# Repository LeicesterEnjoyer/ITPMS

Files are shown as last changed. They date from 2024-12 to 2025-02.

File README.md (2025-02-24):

# ITPMS

## A lightweight, energy-efficient **Improved TPMS with integrated tire wear assistant (ITPMS)**. Designed for universal compatibility and precision.

## 🔥 Key Features

- **🏋️ Ultra-Compact Design**  
    Minimal weight (<30g) ensures compatibility with most tires without affecting balance.

- **📡 Autonomous Operation**  
    Wakes up via accelerometer motion detection → close to none battery drain when stationary.

- **📊 Fast And Precise**  
    Uses device computing from sensors such as:
    - Pressure sensor
    - Temperature sensor (built into the MCU)
    - 3-axis accelerometer
    - Hall effect sensor

- **🔋 10-Year Battery Life**  
    Has low-powered elements and works only while the vehicle is moving.

- **🎯 Hall Effect Initialization**  
    Quick pairing with magnetic TPMS initializing pen.

## 🛠 How It Works

### Installation & Activation

1. **Open** remove the tire from the rim.
2. **Mount** the TPMs on the stem valve inside the tire .
3. **Wake & Pair** the TPMs with the magnetic TPMS initializing pen.
4. **Drive** to see the real time pressure and temperature changes.

### Data Transmission

| Trigger | Action |
|---|---|
| > 5% pressure deviation from last read | Instant RF alert to ECU |
| > 5% temperature deviation from last read | Instant RF alert to ECU |
| 10s without any significant changes | Keep-alive ping |

## 🔍 Code library

ITPMS/  
├── [Assistant/](Assistant/)&nbsp;&nbsp;&nbsp;&nbsp;&nbsp;&nbsp;&nbsp;&nbsp;&nbsp;&nbsp;&nbsp;&nbsp;&nbsp;&nbsp;&nbsp;&nbsp;&nbsp;&nbsp;&nbsp;&nbsp;&nbsp;&nbsp;&nbsp;&nbsp;&nbsp;&nbsp;&nbsp;&nbsp;&nbsp;&nbsp;&nbsp;&nbsp;# All files for the tire wear assistant.  
│&nbsp;&nbsp;&nbsp;├── [assets/](Assistant/assets/)&nbsp;&nbsp;&nbsp;&nbsp;&nbsp;&nbsp;&nbsp;&nbsp;&nbsp;&nbsp;&nbsp;&nbsp;&nbsp;&nbsp;&nbsp;&nbsp;&nbsp;&nbsp;&nbsp;&nbsp;&nbsp;&nbsp;&nbsp;&nbsp;&nbsp;&nbsp;&nbsp;&nbsp;&nbsp;&nbsp;&nbsp;# Assets for the UI.  
│&nbsp;&nbsp;&nbsp;├── [CSVhandling/](Assistant/CSVhandling/)  
│&nbsp;&nbsp;&nbsp;│&nbsp;&nbsp;&nbsp;&nbsp;|── [CSVmanager.py](Assistant/CSVhandling/CSVmanager.py)&nbsp;&nbsp;&nbsp;&nbsp;&nbsp;&nbsp;&nbsp;&nbsp;&nbsp;&nbsp;&nbsp;&nbsp;# Read and write operations for csv files.  
│&nbsp;&nbsp;&nbsp;│&nbsp;&nbsp;&nbsp;└── [DataGenerator.py](Assistant/CSVhandling/DataGenerator.py)&nbsp;&nbsp;&nbsp;&nbsp;&nbsp;&nbsp;&nbsp;&nbsp;# Generator for (TPMs) tire data.  
│&nbsp;&nbsp;&nbsp;│  
│&nbsp;&nbsp;&nbsp;├── [Data/](Assistant/Data/)&nbsp;&nbsp;&nbsp;&nbsp;&nbsp;&nbsp;&nbsp;&nbsp;&nbsp;&nbsp;&nbsp;&nbsp;&nbsp;&nbsp;&nbsp;&nbsp;&nbsp;&nbsp;&nbsp;&nbsp;&nbsp;&nbsp;&nbsp;&nbsp;&nbsp;&nbsp;&nbsp;&nbsp;&nbsp;&nbsp;&nbsp;&nbsp;# Data files for the different tire types and seasons.  
│&nbsp;&nbsp;&nbsp;├── [Tests/](Assistant/Tests/)&nbsp;&nbsp;&nbsp;&nbsp;&nbsp;&nbsp;&nbsp;&nbsp;&nbsp;&nbsp;&nbsp;&nbsp;&nbsp;&nbsp;&nbsp;&nbsp;&nbsp;&nbsp;&nbsp;&nbsp;&nbsp;&nbsp;&nbsp;&nbsp;&nbsp;&nbsp;&nbsp;&nbsp;&nbsp;&nbsp;&nbsp;&nbsp;# Tests for the functionalities of the TPMs classes.  
│&nbsp;&nbsp;&nbsp;├── [TPMsHandling/](Assistant/TPMsHandling/)  
│&nbsp;&nbsp;&nbsp;│&nbsp;&nbsp;&nbsp;&nbsp;|── [Tire.py](Assistant/TPMsHandling/Tire.py)&nbsp;&nbsp;&nbsp;&nbsp;&nbsp;&nbsp;&nbsp;&nbsp;&nbsp;&nbsp;&nbsp;&nbsp;&nbsp;&nbsp;&nbsp;&nbsp;&nbsp;&nbsp;&nbsp;&nbsp;&nbsp;&nbsp;&nbsp;&nbsp;&nbsp;&nbsp;# Represents the tire (TPMs).  
│&nbsp;&nbsp;&nbsp;│&nbsp;&nbsp;&nbsp;└── [Tires.py](Assistant/TPMsHandling/Tires.py)&nbsp;&nbsp;&nbsp;&nbsp;&nbsp;&nbsp;&nbsp;&nbsp;&nbsp;&nbsp;&nbsp;&nbsp;&nbsp;&nbsp;&nbsp;&nbsp;&nbsp;&nbsp;&nbsp;&nbsp;&nbsp;&nbsp;&nbsp;&nbsp;# Represents the tire complect of the vehicle.  
│&nbsp;&nbsp;&nbsp;│  
│&nbsp;&nbsp;&nbsp;├── [Main.py](Assistant/Main.py)&nbsp;&nbsp;&nbsp;&nbsp;&nbsp;&nbsp;&nbsp;&nbsp;&nbsp;&nbsp;&nbsp;&nbsp;&nbsp;&nbsp;&nbsp;&nbsp;&nbsp;&nbsp;&nbsp;&nbsp;&nbsp;&nbsp;&nbsp;&nbsp;&nbsp;&nbsp;&nbsp;&nbsp;# Runs the needed code and tests.  
│&nbsp;&nbsp;&nbsp;└── [TireAssistantGUI.py](Assistant/TireAssistantGUI.py)&nbsp;&nbsp;&nbsp;&nbsp;&nbsp;&nbsp;&nbsp;&nbsp;&nbsp;&nbsp;# UI for the assistant. (*Run the file to start it.)  
│  
├── [CAD/](CAD/)&nbsp;&nbsp;&nbsp;&nbsp;&nbsp;&nbsp;&nbsp;&nbsp;&nbsp;&nbsp;&nbsp;&nbsp;&nbsp;&nbsp;&nbsp;&nbsp;&nbsp;&nbsp;&nbsp;&nbsp;&nbsp;&nbsp;&nbsp;&nbsp;&nbsp;&nbsp;&nbsp;&nbsp;&nbsp;&nbsp;&nbsp;&nbsp;&nbsp;&nbsp;&nbsp;&nbsp;&nbsp;&nbsp;# KiCad models of the pcb.  
├── [Datasheets/](Datasheets/)&nbsp;&nbsp;&nbsp;&nbsp;&nbsp;&nbsp;&nbsp;&nbsp;&nbsp;&nbsp;&nbsp;&nbsp;&nbsp;&nbsp;&nbsp;&nbsp;&nbsp;&nbsp;&nbsp;&nbsp;&nbsp;&nbsp;&nbsp;&nbsp;&nbsp;&nbsp;&nbsp;# Datasheets of all components used in the pcb.  
├── [TPMS&TPMs/](TPMS&TPMs/)&nbsp;&nbsp;&nbsp;&nbsp;&nbsp;&nbsp;&nbsp;&nbsp;&nbsp;&nbsp;&nbsp;&nbsp;&nbsp;&nbsp;&nbsp;&nbsp;&nbsp;&nbsp;&nbsp;&nbsp;&nbsp;&nbsp;&nbsp;&nbsp;# All files and libraries used by the hardware.  
│&nbsp;&nbsp;&nbsp;├── [Code](TPMS&TPMs/Code/)/  
│&nbsp;&nbsp;&nbsp;│&nbsp;&nbsp;&nbsp;&nbsp;|── [Receiver.ino](TPMS&TPMs/Code/Receiver.ino)&nbsp;&nbsp;&nbsp;&nbsp;&nbsp;&nbsp;&nbsp;&nbsp;&nbsp;&nbsp;&nbsp;&nbsp;&nbsp;&nbsp;&nbsp;&nbsp;&nbsp;# Receiver algorithm.  
│&nbsp;&nbsp;&nbsp;│&nbsp;&nbsp;&nbsp;└── [Transmitter.ino](TPMS&TPMs/Code/Transmitter.ino)&nbsp;&nbsp;&nbsp;&nbsp;&nbsp;&nbsp;&nbsp;&nbsp;&nbsp;&nbsp;&nbsp;&nbsp;# Transmitter algorithm.  
│&nbsp;&nbsp;&nbsp;├── [Libraries/](TPMS&TPMs/Libraries/)  
│&nbsp;&nbsp;&nbsp;│&nbsp;&nbsp;&nbsp;&nbsp;├── [Receiver/](TPMS&TPMs/Libraries/Receiver/)&nbsp;&nbsp;&nbsp;&nbsp;&nbsp;&nbsp;&nbsp;&nbsp;&nbsp;&nbsp;&nbsp;&nbsp;&nbsp;&nbsp;&nbsp;&nbsp;&nbsp;&nbsp;&nbsp;&nbsp;# Receiver libraries.  
│&nbsp;&nbsp;&nbsp;│&nbsp;&nbsp;&nbsp;&nbsp;├── [TPMs/](TPMS&TPMs/Libraries/TPMs/)&nbsp;&nbsp;&nbsp;&nbsp;&nbsp;&nbsp;&nbsp;&nbsp;&nbsp;&nbsp;&nbsp;&nbsp;&nbsp;&nbsp;&nbsp;&nbsp;&nbsp;&nbsp;&nbsp;&nbsp;&nbsp;&nbsp;&nbsp;&nbsp;# Transmitter libraries.  
│&nbsp;&nbsp;&nbsp;│&nbsp;&nbsp;&nbsp;&nbsp;└── [TPMS_structures.h](TPMS&TPMs/Libraries/TPMS_structures.h)&nbsp;&nbsp;&nbsp;&nbsp;&nbsp;# Common configuration.  
│  
├── [LICENSE](LICENSE)  
├── [README.md](README.md)&nbsp;&nbsp;&nbsp;&nbsp;&nbsp;&nbsp;&nbsp;&nbsp;&nbsp;&nbsp;&nbsp;&nbsp;&nbsp;&nbsp;&nbsp;&nbsp;&nbsp;&nbsp;&nbsp;&nbsp;&nbsp;&nbsp;&nbsp;&nbsp;&nbsp;&nbsp;# You're here!  
└── [requirements.txt](requirements.txt)&nbsp;&nbsp;&nbsp;&nbsp;&nbsp;&nbsp;&nbsp;&nbsp;&nbsp;&nbsp;&nbsp;&nbsp;&nbsp;&nbsp;&nbsp;&nbsp;&nbsp;&nbsp;&nbsp;&nbsp;# Python dependencies.  

## 🔑 Setup

### Assistant

Run this command to download the needed dependencies:
```sh
pip install -r .requirements.txt
```
After that you can run the UI with:
```sh
python Assistant/TireAssistantGUI.py
```

### TPMS & TPMs

The software must be flashed on a special TPMs via SPI programmer. From there you have to follow the steps in [Installation & Activation](#installation--activation) an you will be ready to use it.

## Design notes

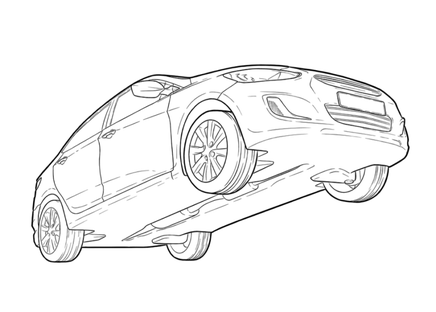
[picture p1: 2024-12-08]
Assistant/assets/image.png

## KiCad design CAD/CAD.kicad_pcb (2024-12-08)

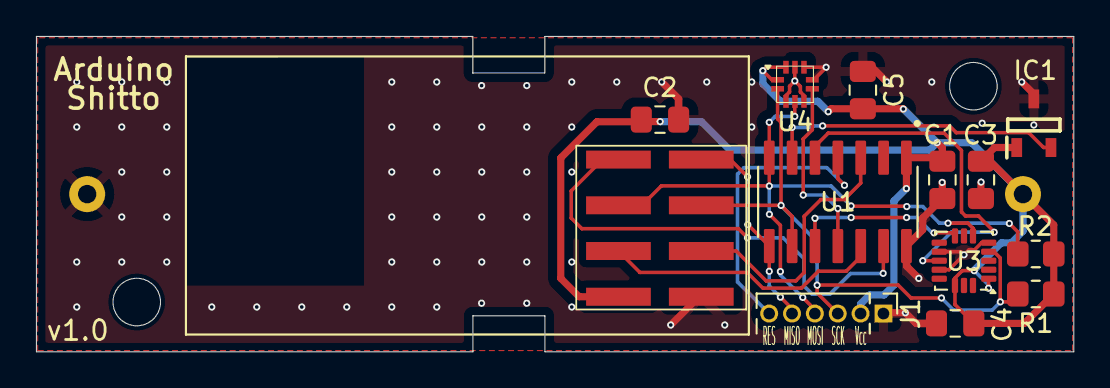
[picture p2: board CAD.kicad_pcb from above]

Board: 2 copper layers, 57.6 x 17.5 mm, 14 parts (1 on the bottom side), 13 nets.

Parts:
BT1: 2460; BAT_2460
C1, C3, C4, C5: 100nF; C_0805_2012Metric_Pad1.18x1.45mm_HandSolder
C2: 10µF; C_0805_2012Metric_Pad1.18x1.45mm_HandSolder
IC1: Si7201-B-04-IV; SOT95P275X125-3N
J1: Conn_01x06_Pin; PinHeader_1x06_P1.27mm_Vertical
R1, R2: 10kΩ; R_0805_2012Metric_Pad1.20x1.40mm_HandSolder
U1: ATTINY84-20SSU; SOIC127P600X175-14N
U2: NRF24L01_Breakout; nRF24L01_Breakout
U3: LIS3DH; LGA-16_3x3mm_P0.5mm_LayoutBorder3x5y
U4: ILPS22QS; ILPS22QSTR

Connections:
3.6V: BT1.P, C1.2, C2.2, C3.2, C4.2, C5.2, IC1.1 (VDD), J1.2, R1.1, R2.1, U1.1 (VCC), U2.2 (VCC), U3.1 (VDD_IO), U3.14 (VDD), U4.1 (Vdd_IO), U4.10 (Vdd)
/CE: U1.3 (PB1), U2.3 (CE)
/CS/A: U1.10 (PA3), U3.8 (CS)
/CS/P: U1.11 (PA2), U4.6 (CS)
/CS/RF: U1.12 (PA1), U2.4 (~CSN)
/INT_ACC: U1.5 (PB2), U3.11 (INT1)
/INT_HALL: IC1.2 (OUT1), U1.6 (PA7)
/IRQ: U1.13 (PA0), U2.8 (IRQ)
/MISO: J1.5, U1.8 (PA5), U2.7 (MISO)
/MOSI: J1.4, R2.2, U1.7 (PA6), U2.6 (MOSI), U3.6 (SDI), U4.4 (SDA)
/RESET: J1.6, U1.4 (PB3)
/SCK: J1.3, R1.2, U1.9 (PA4), U2.5 (SCK), U3.4 (SPC), U4.2 (SCK)
GND: BT1.N, C1.1, C2.1, C3.1, C4.1, C5.1, IC1.3 (GND), J1.1, U1.14 (GND), U2.1 (GND), U3.5 (GND), U3.10 (GND), U3.12 (GND), U4.3 (RES), U4.5 (AH2/QVAR2), U4.7 (AH1/QVAR1), U4.8 (GND_IO), U4.9 (GND)

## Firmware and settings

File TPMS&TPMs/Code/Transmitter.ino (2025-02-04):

#include <TPMS_T_config.h>
#include <TPMS_structures.h>


RF24 radio(RF_CE, RF_CSN);

volatile bool hasToInit = true;
volatile uint8_t INTtrigger = 0, prevINTtrigger = 0;

struct {
  char code;
} ack;

void setupInterrupts() {
  cli();
  MCUCR |= (1 << ISC01); // Enable INT0 on falling edge.
  GIMSK |= (1 << INT0) | (1 << PCIE0); // Enable INT0 and pin change interrupts.

  PCMSK0 |= (1 << PCINT7); // Enable pin change interrupt on PA7.
  sei();
}

ISR(INT0_vect) {
  INTtrigger++;
}

ISR(PCINT0_vect) {
  hasToInit = true;
}

void setupMCU() {
  MCUCR |= (1 << SM1); // When "sleep" is executed the MCU goes in power down mode.

  ADMUX |= (1 << REFS1) | (1 << MUX5) | (1 << MUX1); // Enable the temperature sensor.
  ADCSRA = (1 << ADEN) | (1 << ADPS1) | (1 << ADPS0); // Enable the ADC with on 125kHz.

  // Configure pins.
  DDRA |= (1 << DDA3) | (1 << DDA2); // Configure CS/A and CS/P as outputs.
  PORTA |= (1 << PORTA3) | (1 << PORTA2); // Set CS on both I2C devices to 1.

  // Configure the INT0 as output.
  DDRB &= ~(1 << DDB2);
  PORTB |= (1 << PORTB2); // Enable internal pull-up resistor.

  setupInterrupts();
}

void sleepMCU() {
  MCUCR |= (1 << SE);
  __asm__ __volatile__("sleep");
  MCUCR &= ~(1 << SE);
}

void setupRF() {
  if (!radio.begin())
    PORTB |= (1 << PORTB0);

  radio.setChannel(CHANNEL);
  radio.setRadiation(RF24_PA_MIN, RF24_250KBPS);

  radio.setRetries(15, 15);
  radio.getDynamicPayloadSize();
  radio.enableAckPayload();
  // radio.setAutoAck(false);

  radio.openWritingPipe(identity.address);
  radio.stopListening();
}

void sleepRF() {
  radio.powerDown();
}

void wakeRF() {
  radio.powerUp();
}

void setupPressure() {
  writeRegister(PRESSURE_ADDR, 0x20, (1 << 6)); // Enable full scale mode (4060 hPa).
  writeRegister(PRESSURE_ADDR, 0x10, (1 << 4)); // Configure the pressure sensor with AVG = 4 and ODR = 4 Hz.
  writeRegister(PRESSURE_ADDR, 0x5F, 0x00); // Disable AH1/QVAR1 and AH2/QVAR2.
}

void sleepPressure() {
  writeRegister(PRESSURE_ADDR, 0x10, 0); // Writing '0000' in ODR configures the pressure sensor to power-down mode.
}

void wakePressure() {
  writeRegister(PRESSURE_ADDR, 0x10, (1 << 4)); // Configure the pressure sensor with AVG = 4 and ODR = 4 Hz.
}

void setupACC() {
  writeRegister(ACC_ADDR, 0x20, (1 << 5) | (1 << 3) | (1 << 1) | (1 << 0)); // Configure the accelerometer to work on Low-power mode (10 Hz) and enable it to work on Y and X axes.
  writeRegister(ACC_ADDR, 0x22, (1 << 6)); // Route interrupt to INT1 pin.
  writeRegister(ACC_ADDR, 0x30, (1 << 3) | (1 << 2) | (1 << 1) | (1 << 0)); // Configure INT1 to generate interrupt on movement on both axises.
  writeRegister(ACC_ADDR, 0x32, (1 << 2) | (1 << 1)); // Configure the sensitivity 96 mg @ ±2g.
  writeRegister(ACC_ADDR, 0x33, (1 << 0)); // Configure a 100 ms duration so the noise is ignored.
  writeRegister(ACC_ADDR, 0x26, (1 << 1)); // Configure INT polarity to active low.
}

void writeRegister(const byte address, const byte reg, const byte value) {
  Wire.begin();

  Wire.beginTransmission(address);
  Wire.write(reg);
  Wire.write(value);
  Wire.endTransmission();

  Wire.end();
}

byte readRegister(const byte address, const byte reg) {
  Wire.begin();

  Wire.beginTransmission(address);
  Wire.write(reg);
  Wire.endTransmission(false); // "False" keeps the connection open.
  
  Wire.requestFrom(address, 1);
  byte result = 0x00;
  if (Wire.available()) 
    result = Wire.read();
  
  Wire.end();
  return result;
}

void sleepTPMs() {
  sleepRF();
  sleepPressure();
  sleepMCU();
}

void getPressure() {
  uint16_t pressureSum = 0;
  
  for (uint8_t measCnt = 0; measCnt != NUMBER_OF_MEAS; ++measCnt) {
    // Use the given formula in the datasheet for pressure calculation.
    uint32_t pressure = (readRegister(PRESSURE_ADDR, 0x2A) << 16) | (readRegister(PRESSURE_ADDR, 0x29) << 8) | readRegister(PRESSURE_ADDR, 0x28);
    pressure /= 2048;
    pressure /= 10; // Convert to kPa.

    pressureSum += pressure;
  }

  payload.pressure = pressureSum / NUMBER_OF_MEAS >> 1; // >> 1 so it fits in 1 byte (406 kPa is the largest value).
}

void getTemp() {
  int16_t tempSum = 0;
  
  for (uint8_t measCnt = 0; measCnt != NUMBER_OF_MEAS; ++measCnt) {
    ADCSRA |= (1 << ADSC); // Begin measurement.
    while (ADCSRA & (1 << ADSC)); // Wait for measure (the ADCL bit returns to 0 ones the conversion is completed).

    tempSum += ((ADCH << 8) | ADCL);
  }

  payload.temp = tempSum / NUMBER_OF_MEAS - 44; // Using a temperature offset.
}

void gatherPayload() {
  getTemp();
  getPressure();
}

bool changeInPressureOrTemp() {
  static int8_t prevTemp = 0;
  static uint16_t prevPressure = 0;

  if (abs((payload.pressure << 1) - prevPressure) >= prevPressure * 0.05
      || abs(payload.temp - prevTemp) >= prevTemp * 0.05)
  {
    prevPressure = (payload.pressure << 1);
    prevTemp = payload.temp;
    
    return true;
  }
  
  return false;
}

void OVFcorrection(uint32_t *current_ms, uint32_t *keepAlive_ms, uint32_t *prevTemp_ms, uint32_t *prevPressure_ms, uint32_t *prevINT_ms) {
  if (*current_ms >= *keepAlive_ms)
    return;
    
  *current_ms = *keepAlive_ms = *prevTemp_ms = *prevPressure_ms = *prevINT_ms = 0;
}

void interruptCheck(const uint32_t current_ms, uint32_t *prevINT_ms) {
  if (INTtrigger <= prevINTtrigger) 
    return;
  
  prevINTtrigger++;
  *prevINT_ms = current_ms;
}

void setup() {
  // Setup debug pin.
  DDRB |= (1 << DDB0);
  PORTB &= ~(1 << PORTB0);

  setupMCU(); 
  setupRF();
  setupPressure();
  setupACC();
  
  sleepTPMs();
}

void loop() {
  static uint32_t current_ms = 0, keepAlive_ms = 0, prevTemp_ms = 0, prevPressure_ms = 0, prevINT_ms = 0;
  current_ms = millis();

  OVFcorrection(&current_ms, &keepAlive_ms, &prevTemp_ms, &prevPressure_ms, &prevINT_ms);
  
  if (!hasToInit) {
    interruptCheck(current_ms, &prevINT_ms);
    if (current_ms - prevINT_ms >= PREV_INT0_MS)
        sleepTPMs();
  }

  if (hasToInit)
    sendIdentity();

  if (current_ms - prevTemp_ms >= TEMP_MEAS_MS) {
    prevTemp_ms = current_ms;
    getTemp();

    if (changeInPressureOrTemp()) {
      keepAlive_ms = current_ms;
      sendPayload();
    }
  }

  if (current_ms - prevPressure_ms >= PRESSURE_MEAS_MS) {
    prevPressure_ms = current_ms;
    getPressure();

    if (changeInPressureOrTemp()) {
      keepAlive_ms = current_ms;
      sendPayload();
    }
  }

  if (current_ms - keepAlive_ms >= KEEP_ALIVE_MS) {
    keepAlive_ms = current_ms;

    gatherPayload();
    sendPayload();
  }
}

void sendIdentity() {
  wakeRF();

  if (!radio.write(&identity, sizeof(identity))
      || !radio.isAckPayloadAvailable()) 
    return;
  
  if (radio.getDynamicPayloadSize() == 1) {
    sleepTPMs();
    return;
  }

  radio.read(&identity, radio.getDynamicPayloadSize());
  
  radio.setRetries(identity.retransmitDelay, 15);
  radio.openWritingPipe(identity.address);

  hasToInit = false;
  sleepRF();
  return;
}

void sendPayload() {
  wakeRF();

  if (!radio.write(&payload, sizeof(payload))
      || !radio.isAckPayloadAvailable()) 
    return;

  radio.read(&ack, radio.getDynamicPayloadSize());

  sleepRF();
  return;
}

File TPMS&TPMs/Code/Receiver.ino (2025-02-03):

#include <Tires.h>
#include <TPMS_structures.h>


RF24 radio(RF_CE, RF_CSN);


void clearEEPROM() {
  for (uint16_t i = 0; i < EEPROM.length(); ++i) {
    if (EEPROM.read(i) == 0xFF)
      break;
    EEPROM.write(i, 0xFF);
  }
}

void removeGarbage() {
  byte garbage[32];
  radio.read(&garbage, radio.getDynamicPayloadSize());
}

void setup() {
  Serial.begin(9600);
  while (!Serial);

  randomSeed(analogRead(A0)); // Seed randomness with floating analog pin.

  // Begin communication with the RF module.
  if (!radio.begin())
    Serial.println("Couldn't establish connection with the RF module.");
  
  radio.setChannel(CHANNEL);
  radio.setRadiation(RF24_PA_MIN, RF24_250KBPS);

  radio.getDynamicPayloadSize();
  radio.enableAckPayload();
  // radio.setAutoAck(false);

  const byte broadAddress[ADDRESS_LEN] = {'B', 'R', 'O', 'A', 'D'};

  radio.openReadingPipe(0, broadAddress);
  radio.startListening();

  // For debugging purposes only.
  // clearEEPROM(); 

  Serial.println("Connection established!");
}

void loop() {
  static tires_t tires;
  static char tireComplect = '0';
  static const char* positions[] = {"front left", "front right", "rear right", "rear left"};
  uint8_t pipe;
  
  static uint32_t current_ms = 0, lastReceived_ms[TIRES] = { 0 };
  static bool isInitializing = true, reinitialize = false, isMoving = true, synchronized = true;
  
  // isMoving comes from the automobile itself and checks if we are moving so we can synchronize the time between recieves.
  if (!isMoving)
    synchronized = false;

  if (!synchronized && isMoving) {
    uint32_t syncTime = millis();

    for (uint8_t i = 0; i < TIRES; ++i) 
      lastReceived_ms[i] = syncTime;
    synchronized = true;
  }

  current_ms = millis();

  // Check for a message in the RX fifo.
  if (radio.available(&pipe)) {
    if (!isInitializing) {
      if (radio.getDynamicPayloadSize() != sizeof(payload)) {
        removeGarbage();
        return;
      }
      
      lastReceived_ms[pipe - 1] = current_ms;

      static uint16_t prevPressure = payload.pressure << 1;
      static int8_t prevTemp = payload.temp;

      // Receive payload from TPMs (a tire).
      memset(&payload, 0, sizeof(payload));
      radio.read(&payload, sizeof(payload));

      Serial.print("Rceived payload from ");
      Serial.print(positions[pipe - 1]);
      Serial.println(":");
      Serial.print("Temperature: ");
      Serial.println(payload.temp);
      Serial.print("Pressure: ");
      Serial.println((payload.pressure << 1) / 1000); // To convert back to kPa -> y = (x << 1) and than to bar -> (y / 100).

      if (abs(payload.pressure - prevPressure) >= prevPressure * 0.1
          || abs(payload.temp - prevTemp) >= abs(prevTemp) * 0.1)
      {
        Serial.println("<Warning on the infotainment>");
        Serial.print("Unusual temperature or pressure changes detected on the ");
        Serial.print(positions[pipe]);
        Serial.println(" tire!");
        Serial.println("Check if everything is fine, before continuing to drive!");
        Serial.println("<Waiting for driver to close the warning from the infotainment>");

        prevPressure = payload.pressure;
        prevTemp = payload.temp;
      }
    }

    // The initialization is enabled by the driver from the infotainment.
    else {
      static uint8_t position = 0;

      // Receive identity from TPMs (a tire).
      memset(&identity, 0, sizeof(identity));
      radio.read(&identity, sizeof(identity));

      // For debugging purposes only.
      Serial.println("Received identity: ");
      Serial.print("Address: ");
      Serial.println((char *)identity.address);
      Serial.print("Retransmit Delay: ");
      Serial.println((char *)identity.retransmitDelay);

      // Driver must choose the tire complect. Valid options: 's' - summer; 'w' - winter.
      if (tireComplect == '0') {
        Serial.println("<Warning on the infotainment>");
        Serial.println("Choose tire complect!");
        Serial.println("<Waiting for driver's decision from the infotainment>");
      }
       
    
      // Select tire complect if possible (if has been used before). If 'selectTires()' returns false save the corresponding marker.  
      if (!selectTires(&tires, tireComplect))
        if (tireComplect == 's')
          EEPROM.write(SUMMER_MARKER_ADDR, SUMMER_MARKER);
        else
          EEPROM.write(WINTER_MARKER_ADDR, WINTER_MARKER);

      // Check if the current tire is already in that position.
      if (!checkTirePosition(tires, position, identity.address)) {
        // Check if the tire address is "BROAD". If it is than the tire is being initialized for the first time.
        if (memcmp(identity.address, "BROAD", sizeof(identity.address)) == 0) {
          initTier(&tires, position); // Initialize the tire with its position and unique address.

          // Load the initialized values in the identity.
          memset(&identity, 0, sizeof(identity));
          memcpy(identity.address, tires.tire[position].address, ADDRESS_LEN);
          identity.retransmitDelay = tires.tire[position].retransmitDelay;

          radio.writeAckPayload(0, &identity, sizeof(identity)); // Return the ACK with the initialized identity.
          radio.openReadingPipe(position + 1, tires.tire[position].address); // Open a new pipe for secure communication with the tire.
        }
        // If the address isn's "BROAD" the tire has been initialized before.
        else {
          // Wait for the driver's response.
          Serial.println("<Warning on the infotainment>");
          Serial.println("The tire that is currently initializing isn't on it's original position!");
          Serial.print("Would you like to fix this or to reinitialize it on it's new position?");
          Serial.println(" If you choose to reinitialize, this decision will also be valid for the other tires!");
          Serial.println("<Waiting for driver's decision from the infotainment>");

          // If he has selected to reinitialize the tires, all tires will be moved to their current positions (that are different from the their previous ones).
          if (reinitialize) {
            updateTirePosition(&tires, position, identity.address); // Move tire in correct position.
            
            radio.writeAckPayload(0, &identity, sizeof(identity)); // Return the ACK with the initialized identity.
            radio.openReadingPipe(position + 1, tires.tire[position].address); // Open a new pipe for secure communication with the tire.
          }
          // The TPMs sensor goes to sleep and waits for driver to initialize it again by the init pen.
          else {
            radio.writeAckPayload(0, 'S', sizeof('S'));
            return;
          }
        }
      }
      // Check if all tires are initialized.
      if (++position == TIRES) {
        isInitializing = false;
        reinitialize = false;

        Serial.println("All tires have been initialized!");
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

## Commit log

2024-12-08 KiCad project
    [CAD.kicad_pcb, CAD.kicad_sch]
2024-12-08 Tire class for TPMs data handling + unit tests
2024-12-09 Tires class for TPMs data handling + unit tests
2024-12-09 CSV handling
    [SummerTiresData.csv]
2024-12-12 Small changes
    [SUMMER.csv, SummerTiresData.csv]
2024-12-12 GUI functionalities
    [WINTER.csv]
2025-01-30 Moved the assistant code in separate directory
    [SUMMER.csv, WINTER.csv]
2025-01-30 Moved the Main and TireAssistantGUI files too
